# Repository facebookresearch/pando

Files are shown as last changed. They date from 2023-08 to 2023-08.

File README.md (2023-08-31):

# Pando
Pando makes it easy to run experiments with and collect data from several different time tagger and SPAD devices. It supports Brain-Machine Interface research and a recent Nature-published research on **Measuring human cerebral blood flow and brain function with fiber-based speckle contrast optical spectroscopy system** can be found [here](https://www.nature.com/articles/s42003-023-05211-4).

Additional documentation can be found [here](https://github.com/facebookresearch/pando/blob/main/software/doc/sphinx_src/).

# Windows Build Tools Installation
1. Get a windows 10 VM [https://developer.microsoft.com/en-us/windows/downloads/virtual-machines]

2. Install Chocolatey [https://chocolatey.org/install]
3. In an administrator powershell, run:

   ```
   choco install -y python3 --version 3.6.8
   New-Item -ItemType SymbolicLink -Path "C:\Python36\python3.exe" -Target "C:\Python36\python.exe"
   choco install -y git buck python2 visualstudio2017-workload-vctools
   ```
4. Restart

# Runtime Dependencies
Libraries and drivers from various vendors must be installed before certain devices can be used. If the correct runtime dependencies are not installed, the result is usually a hard crash when an attempt to configure one of these devices is made.

All Basler cameras require the Pylon runtime v6.3:
https://www.baslerweb.com/en/downloads/software-downloads/runtime-pylon-6-3-0-windows/

Basler CXP-12 acquisition cards (used with the Basler Boost camera) requre the imaWorx CXP-12 Runtime:
https://www.baslerweb.com/en/downloads/software-downloads/complete-installation-5-9-0-windows-64bit/

The microEnable 5 marathon ACL Frame grabber (used with the Basler acA2000-340kM camera) requires this runtime: 
https://www.baslerweb.com/en/downloads/software-downloads/setup-runtime-5-for-windows-64bit-ver-5-7-0/

The Hamamatsu Orca Fusion requires the "Active Silicon Firebird/Phoenix" component of the DCAM-API:
https://ftp.hostedftp.com/~hamamatsu/DCAM-API/2022/22.9/DCAM-API%20for%20Windows%20(22.9.6509).zip

# Building Pando GUI
Before building Pando, you must generate `software/pando/include/version.h`
```
buck run @mode/win/x86_64/release //software/python/generate_version_header:generate_version_header -- --header --define-name=JULIET_VERSION_STRING >  software/pando/include/version.h
buck build @mode/win/x86_64/release software/python/gui:pando
```

## Mode Files
Buck a has feature called "mode files" (also known as flag files) that allows multiple command line arguments to be supplied at once by passing a path (preceded by an `@`) to a text file containing them. We use this feature to specify various platforms and build types. Our mode files (and the buckconfig files they reference) are stored in `./mode/`.

If you require debug symbols or want to enable asserts, you could instead specify `@mode/win/x86_64/rel_with_deb_info`. If you want an unoptimized debug build, you could specify `@mode/win/x86_64/debug`.

## Using the Correct Toolchain on Windows
Launch "x64 Native Tools Command Prompt for VS 2017" from the start menu. Buck will (apparently) use the environment variables set by this special command prompt to use the right build tools and compile/link against the right windows SDK. Alternatively, run C:\Program Files (x86)\Microsoft Visual Studio\2017\BuildTools\VC\Auxiliary\Build\vcvars64.bat from a normal command prompt.

# Contributors
Mark Spatz, Ryan Catoen, Dan Furie, Jen Dority, Charles Freeman, Jami Friedman, Rudy Sevile and Jimmy Feng.

**License**:
LabGraph is MIT licensed, as found in the LICENSE file.

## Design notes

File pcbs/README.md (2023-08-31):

# Pando Box PCB Repository

This is meant as a central repository of all PCBs created for the Pando Box

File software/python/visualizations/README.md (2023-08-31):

# How to run the Basler and Hamamatsu visualizations from source

## Installing Visualization Source Distribution

0. (First time only) Create a new python virtual environment for running the visualizations.

``` python -m venv C:\vizenv```
1. Activate the visualization virtual python environment you created.

```<drive>:\<virtual-environment-path>\Scripts\activate.bat```

where <drive> and <virtual-environment-path> are replaced by the drive and the path to the virtual environment you created in step 0.

2. Extract all files in visualizations.zip

3. Open a command prompt and change directory to the directory where the contents of the zip file were extracted.

4. ```pip install labgraph\<labgraph-wheel-name>```

where <labgraph-wheel-name> is replaced with the correct name of the "*.whl" file delivered in the "labgraph" directory.

5. ```pip install -r bci\example_requirements.txt```
 
If you get an error building "_yappi" extension, follow instructions under *"Installing Microsoft Visual C++ Build Tools"* now and then rerun this step.

# Installing Microsoft Visual C++ Build Tools

1. go to  https://visualstudio.microsoft.com/downloads/

2. Click top row button *"Free Visual Studio"*

3. Click *"Free Download"* under Visual Studio Community

4. Open downloaded file

5. Allow program to make changes to your computer

6. Under *"Desktop and Mobile"* select *"Desktop Development with C++"*

7. Click *"Install"*

# Running Visualizations

## Running Visualizations from the command line

First, make sure you have activated the python virtual environment you created for visualizations.

```<drive>:\<virtual-environment-name>\Scripts\activate.bat```

where <drive> and <virtual-environment-path> are replaced by the drive and the path to the virtual environment you created

**Run the visualizations from the directory where the visualizations.zip contents were extracted.**

Depending on the camera mode and the choice of tcp port, the full command for running the visualization software will likely look something like

```python -m bci.libraries.labgraph_viz.bassler_hamamatsu_viz --camera-mode basler```

The `-m` flag specifies that the script is to be run as a module.  The visualizations will not work without this flag.

`bci.libraries.labgraph_viz.bassler_hamamatsu_viz` is the relative path of the visualization module from the root directory of the visualizations folder.

## Choosing Camera Mode

The `--camera-mode basler` flag informs the visualization software that the message field types and the sizes of the heatmaps should be fitted for basler sized images.  To run the visualizations in hamamatsu mode, change this command to `--camera-mode hamamatsu`.

## Changing the TCP port

There is an optional flag that can be appended to change the tcp port where the visualizations receive incoming messages.  By default, the visualizations expect the messages to appear at `tcp://127.0.0.1:5060`.  However, in order to run both the visualizations for both basler and hamamatsu at the same time, one must ensure that each instance receives the messages at different ports.  This can be accomplished by including the flag `--read-addr tcp://127.0.0.1:5061`.  For instance, one could run the hamamatsu visualizations from messages coming through `tcp://127.0.0.1:5061` using the full command

```python -m bci.libraries.labgraph_viz.bassler_hamamatsu_viz --camera-mode hamamatsu --read-addr tcp://127.0.0.1:5061```

The ability to specify which port the messages are arriving at allows us to run the basler and hamamatsu visualizations in parallel.  Running the two commands

```python -m bci.libraries.labgraph_viz.bassler_hamamatsu_viz --camera-mode basler```

```python -m bci.libraries.labgraph_viz.bassler_hamamatsu_viz --camera-mode hamamatsu --read-addr tcp://127.0.0.1:5061```

concurrently allows for both visualization modes to run concurrently with no conflicts.

# Using the Visualizations

When the visualizations are run, two separate windows should pop up.  One consists of four panels displaying live visualizations for the running camera.  The other is a Region of Interest Selection Utility.

To activate a region of interest in the RoI popup, drag on one of the handles in the upper right or bottom left of the camera live feed.  This will activate (and resize) a region of interest.  The RoI can further be repositioned by clicking and dragging.  Associated updates in the visualizations can be observed upon RoI activation.  

In general, try not to activate any more RoI's than are needed for the experiment.  Calculating the contrast of each region is taxing, and activating too many might lead to performance or stability issues.

Two spinboxes can also be found in the visualization suite.  The one within the RoI popup dictates how long of a rolling average window to maintain.  The one within the main four-panel graph dictates how large of a rolling average window to maintain, as used in normalizing the values when computing the contrast.  Neither of these parameters should have a drastic impact on performance.

Finally, for the sake of stability, try not to run any intensive applications in parallel with the visualizations.  They are very computationally intensive programs that run with stability when run standalone, but using them in conjunction with other high or medium intensity programs, such as heavy duty IDE's or some browsers, might lead to performance issues.  So, avoid this when possible.

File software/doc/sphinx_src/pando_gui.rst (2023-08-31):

.. cpp:namespace:: pnd::pando

==========
Pando GUI
==========
The Pando GUI is a frontend for libpando that presents all of the available settings in a (hopefully) intuitive format.

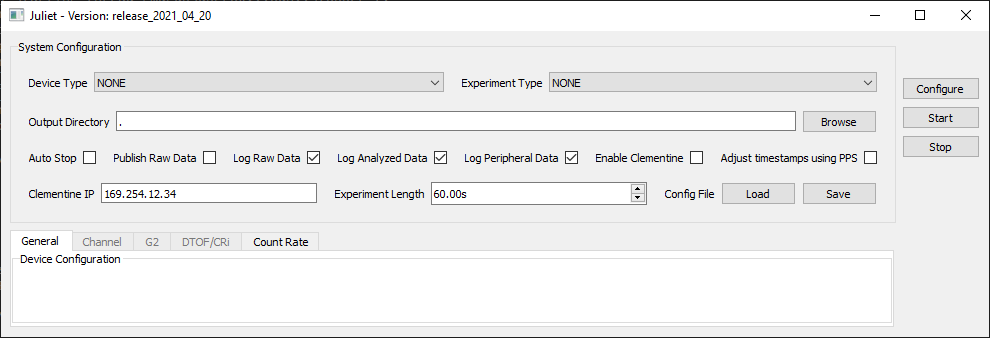
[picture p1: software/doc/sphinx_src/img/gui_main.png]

   
   Screenshot of the Pando GUI

Experiment Control
------------------
Configure
  Applies the current configuration as specified by all other GUI elements.
  Settings don't take effect until either **Configure** or **Start** is clicked.
  See :cpp:func:`PandoInterface::Configure`

Start
  Applies the current configuration, then starts a new experiment.
  See :cpp:func:`PandoInterface::Start`

Stop
  Stop the current experiment and wait until all in-flight data has been written to the HDF5 files.

System Configuration Pane
-------------------------

Config file
  Load/save all settings (from all panes, visible or not) to a YAML file.

.. list-table::
   :header-rows: 1

   * - Setting
     - Description
   * - Device Type
     - See :cpp:member:`PandoInterface::Config::device`
   * - Experiment Type
     - See :cpp:member:`PandoInterface::Config::exp_type`
   * - Output Directory
     - See :cpp:member:`PandoInterface::Config::output_dir`
   * - Auto Stop
     - See :cpp:member:`PandoInterface::Config::auto_stop`
   * - Publish Raw Data
     - See :cpp:member:`PandoInterface::Config::publish_raw_data`
   * - Log Raw Data
     - See :cpp:member:`PandoInterface::Config::log_raw_data`
   * - Log Analyzed Data
     - See :cpp:member:`PandoInterface::Config::log_analyzed_data`
   * - Log Peripheral Data
     - See :cpp:member:`PandoInterface::Config::log_peripheral_data`
   * - Enable Pandoboxd
     - See :cpp:member:`PandoInterface::Config::use_pandoboxd`
   * - Adjust timestamps using PPS
     - See :cpp:member:`PandoInterface::Config::use_pps`
   * - Pandoboxd IP
     - See :cpp:member:`PandoInterface::Config::pandoboxd_ip_addr`
   * - Experiment Length
     - See :cpp:member:`PandoInterface::Config::experiment_length`

General Tab
-----------

Settings related to general device operation.

.. list-table::
   :header-rows: 1

   * - Setting
     - Description
   * - Enabled Channels
     - See :cpp:member:`PandoInterface::Config::enabled_channels`
   * - Laser Sync Rep Period
     - See :cpp:member:`PandoInterface::Config::laser_sync_period_ps`
   * - Sync Divider
     - See :cpp:member:`PandoInterface::Config::xharp_sync_div`

Channel Tab
-----------
Settings related to the individual input channel frontends of PicoQuant devices.

.. list-table::
   :header-rows: 1

   * - Setting
     - Description
   * - Sync (Channel 0) CFD level
     - See :cpp:member:`PandoInterface::Config::xharp_sync_level`
   * - Sync (Channel 0) Zero Crossing level
     - See :cpp:member:`PandoInterface::Config::xharp_sync_zerox`
   * - Channel CFD level
     - See :cpp:member:`PandoInterface::Config::xharp_level`
   * - Channel Zero Crossing
     - See :cpp:member:`PandoInterface::Config::xharp_zerox`
   * - Channel Zero Crossing
     - See :cpp:member:`PandoInterface::Config::xharp_zerox`
   * - Channel Offsets
     - See :cpp:member:`PandoInterface::Config::hharp_input_offsets`

The MultiHarp has unique channel settings (the inputs don't have CFDs):

.. list-table::
   :header-rows: 1

   * - Setting
     - Description
   * - Sync Trigger Edge
     - See :cpp:member:`PandoInterface::Config::multi_harp_sync_trigger_edge`
   * - Sync Trigger Level
     - See :cpp:member:`PandoInterface::Config::multi_harp_sync_trigger_level_mv`
   * - Sync Tdead
     - See :cpp:member:`PandoInterface::Config::multi_harp_sync_tdead_ps`
   * - Trigger edges
     - See :cpp:member:`PandoInterface::Config::multi_harp_sync_trigger_edge`
   * - Trigger Levels
     - See :cpp:member:`PandoInterface::Config::multi_harp_trigger_level_mv`
   * - Tdead
     - See :cpp:member:`PandoInterface::Config::multi_harp_tdead_ps`

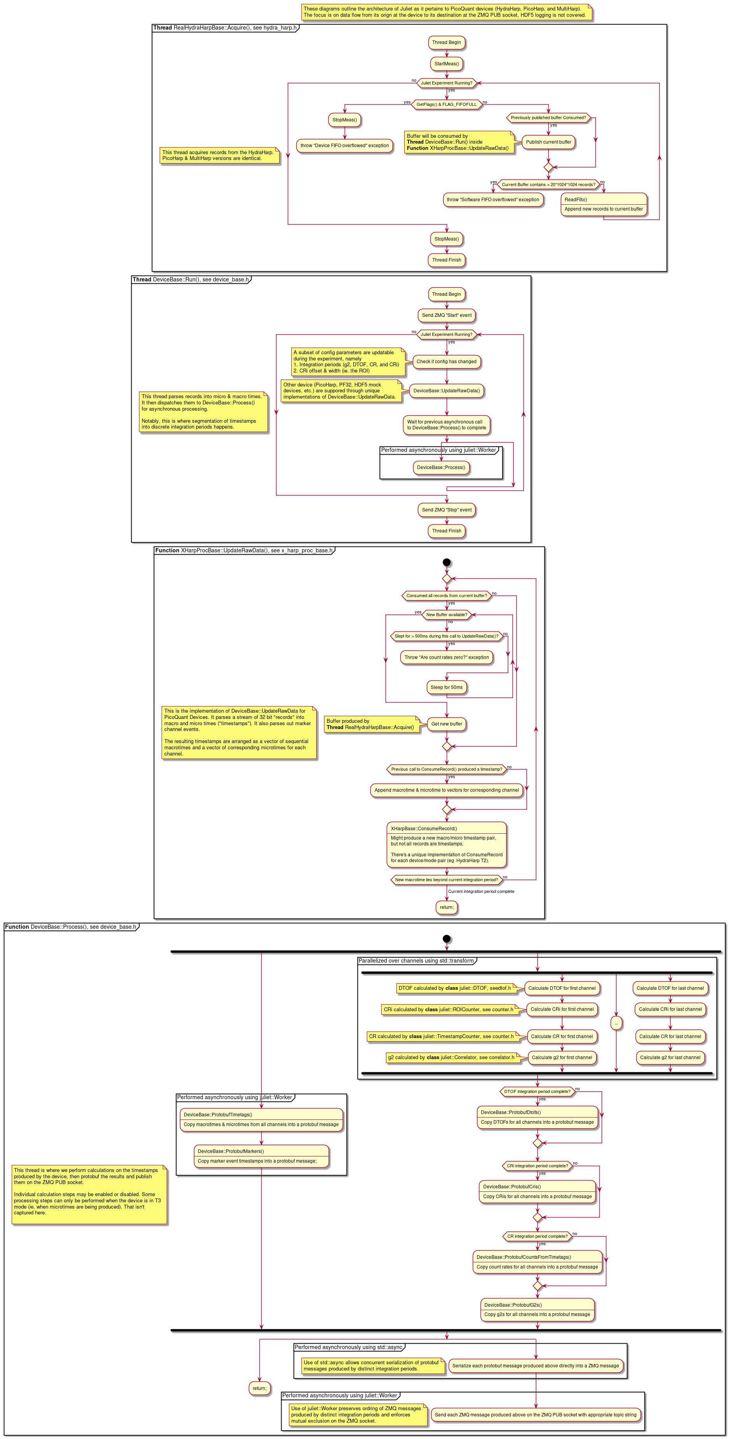
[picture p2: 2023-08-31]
software/pando/doc/architecture.png

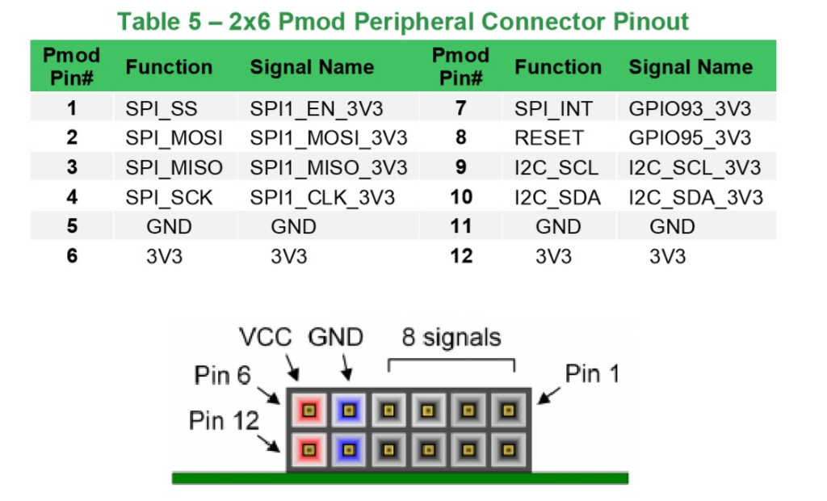
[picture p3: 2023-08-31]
pcbs/SPItoLVDS/Documentation/pmod_pinout.png

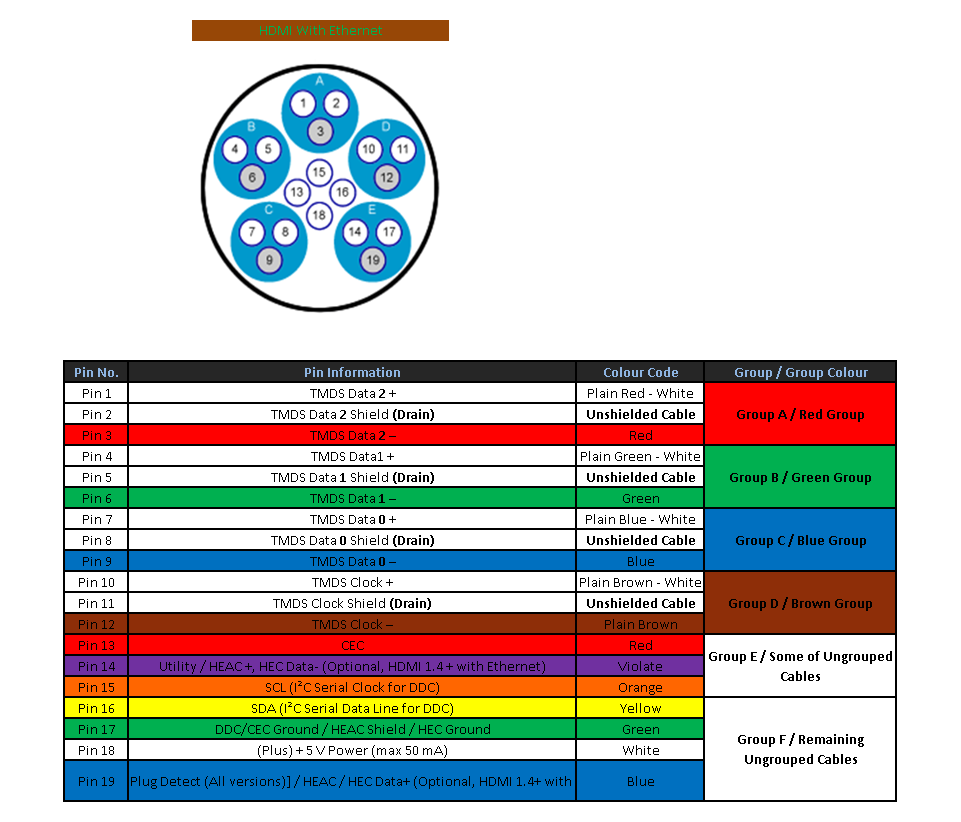
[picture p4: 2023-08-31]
pcbs/RemoteIMU/Documentation/hdmi_pinout.png

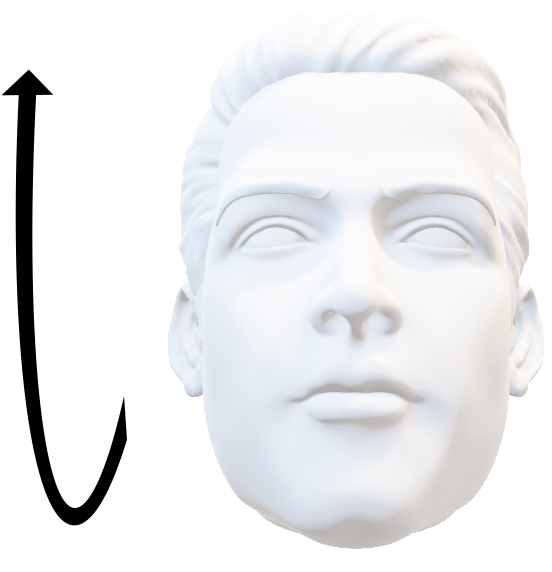
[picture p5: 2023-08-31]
software/python/visualizations/bci/stimulus/psychopy/images/files/pitch_up.png

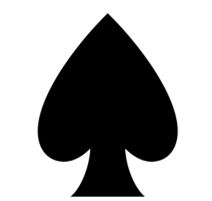
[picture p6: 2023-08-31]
software/python/visualizations/bci/stimulus/psychopy/images/files/spade.png

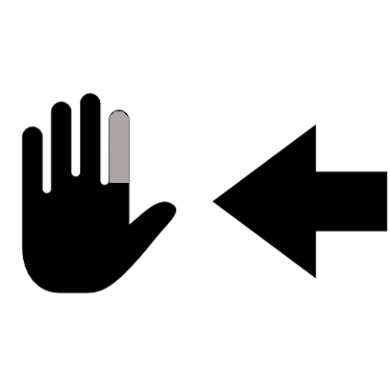
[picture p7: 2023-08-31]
software/python/visualizations/bci/stimulus/psychopy/images/files/index_left.png

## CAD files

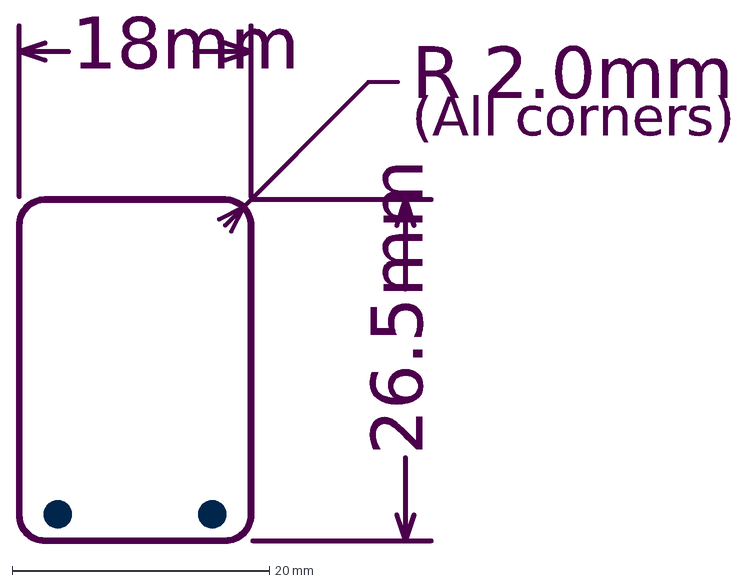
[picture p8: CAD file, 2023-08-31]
pcbs/RemoteIMU/soho_imu_outline.DXF
(All corners)
R 2.0mm
26.5mm
18mm

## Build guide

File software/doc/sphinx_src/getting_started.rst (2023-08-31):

.. cpp:namespace:: pnd::pando

==========
Getting Started with Pando
==========
Pando makes it easy to run experiments with and collect data from several different time tagger and SPAD devices.

This guide will take you step-by-step through running experiments with real devices.

Prerequisites
-------------
Pando runs on Windows and is built as Python pex executable. It requires Python 3 to be installed on the Windows PC.

You must install the drivers for the devices you will be working with.

You must install the latest Microsoft Visual C++ Redistributable for Visual Studio from `here <https://support.microsoft.com/en-us/topic/the-latest-supported-visual-c-downloads-2647da03-1eea-4433-9aff-95f26a218cc0>`_.

Starting Pando
---------------
Open a command prompt (cmd.exe) and navigate to the directory where the pando.pex file is located.

At the prompt, run the command ``python pando.pex``.

The Pando GUI will open: 


   
   Screenshot of the Pando GUI

Selecting a Device and Experiment Type
--------------------------------------
The device and experiment types chosen will determine the what options and defaults are available in some parts of the GUI. For this tutorial, we will be running a TD experiment with PicoQuamt's MultiHarp device.

Once you have set the the device and experiment types, the GUI will update to accommodate devices-specific settings.

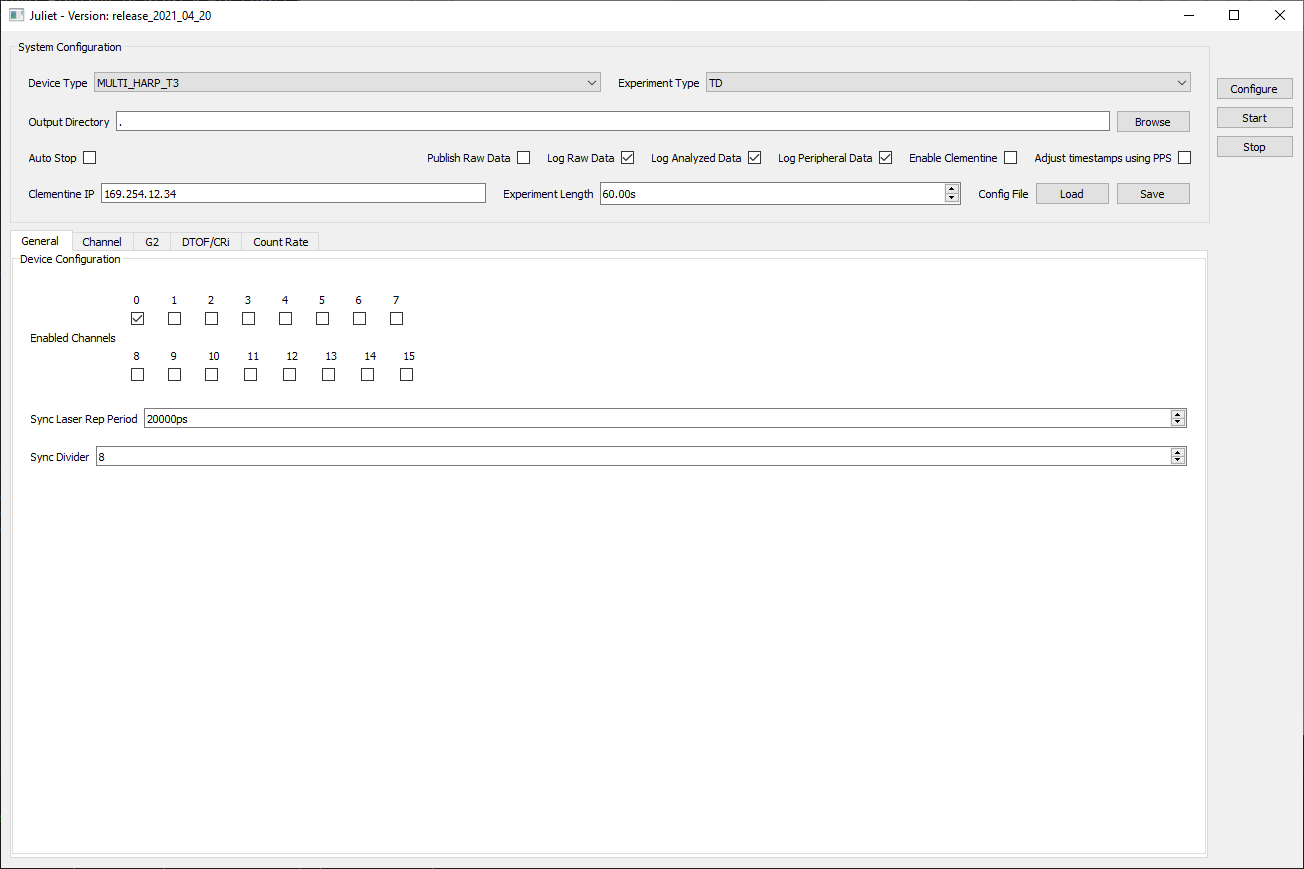
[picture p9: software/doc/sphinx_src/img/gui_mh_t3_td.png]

   
   Pando GUI with Device Type "MULTI_HARP_T3" and Experiment Type "TD" selected

Channel Selection and General Device Configuration
--------------------------------------------------
On the "General" tab in the device configuration section, select the channels to be used by checking the corresponding checkboxes in the "Enabled Channels" area. Data from unselected channels will be ignored. Set an appropriate Sync Divider value, and also the correct Sync Laser Rep Period -- the time in picoseconds between two consecutive sync pulses.

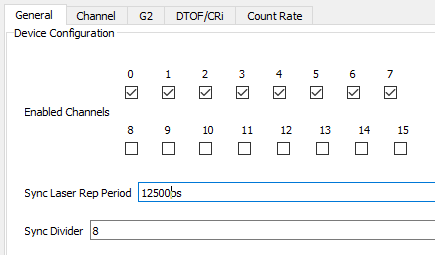
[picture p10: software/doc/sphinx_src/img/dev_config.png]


   Enabled Channels, Sync Laser Rep Period and Sync Divider settings in the "General" tab

Input Channel Configuration
---------------------------
Next, configure the settins per input channel. The settings available on "Channel" ta vary significantly depending on the device type selected. For the MultiHarp device, make sure the Channel Offsets, Trigger Edges, Trigger Levels and programmable dead times are correct for each channel.

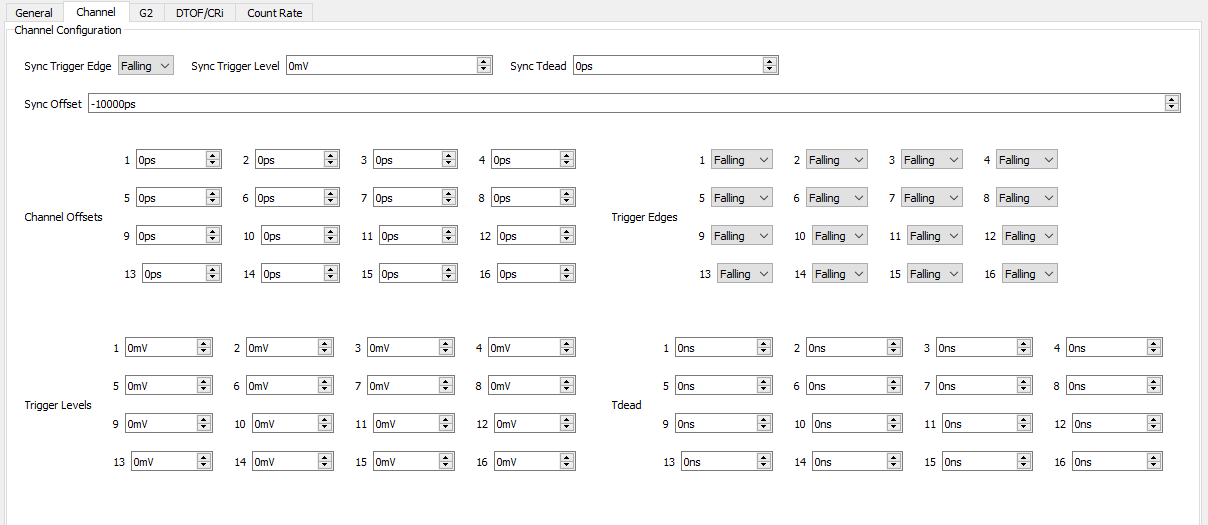
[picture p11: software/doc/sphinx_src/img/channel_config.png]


   Input Channel Configuration for MultiHarp on "Channel" Tab

G2, DToF and CRi
----------------
The last three tabs in the Device Configuration Panel allow you to set parameters for their respective calculations.

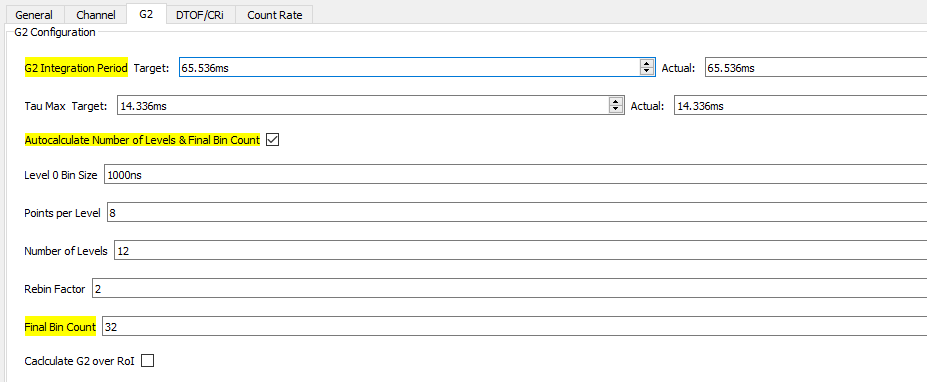
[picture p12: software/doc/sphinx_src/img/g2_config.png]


   G2 Configuration Parameters

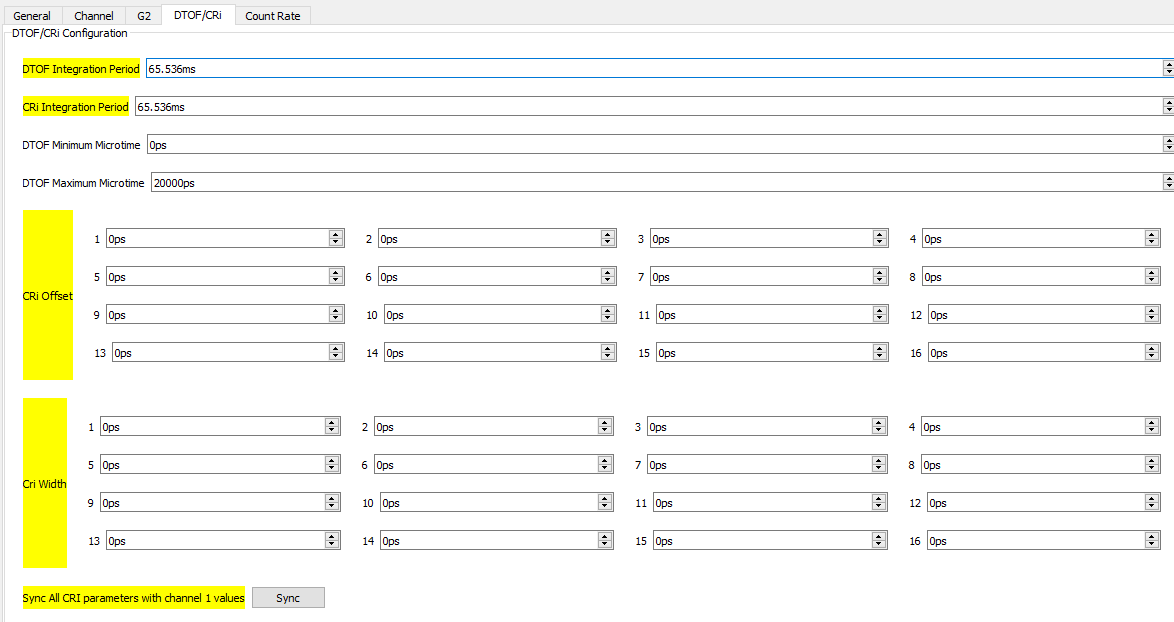
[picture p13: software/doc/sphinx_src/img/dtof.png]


   DToF Configuration Parameters

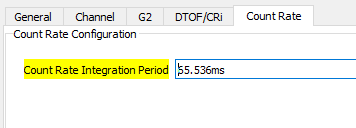
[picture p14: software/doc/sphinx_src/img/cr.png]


   Count Rate Configuration Parameters

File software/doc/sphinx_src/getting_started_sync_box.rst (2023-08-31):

.. cpp:namespace:: pnd::pando

==========
Getting Started with the Sync Box
==========

Ultrazed Setup
--------------
Below is an overview image of the internals of the Sawyer Sync Box, which consists of the UltraZed-EG with IO Carrier card and peripheral interface boards.  Relevant components are labelled.

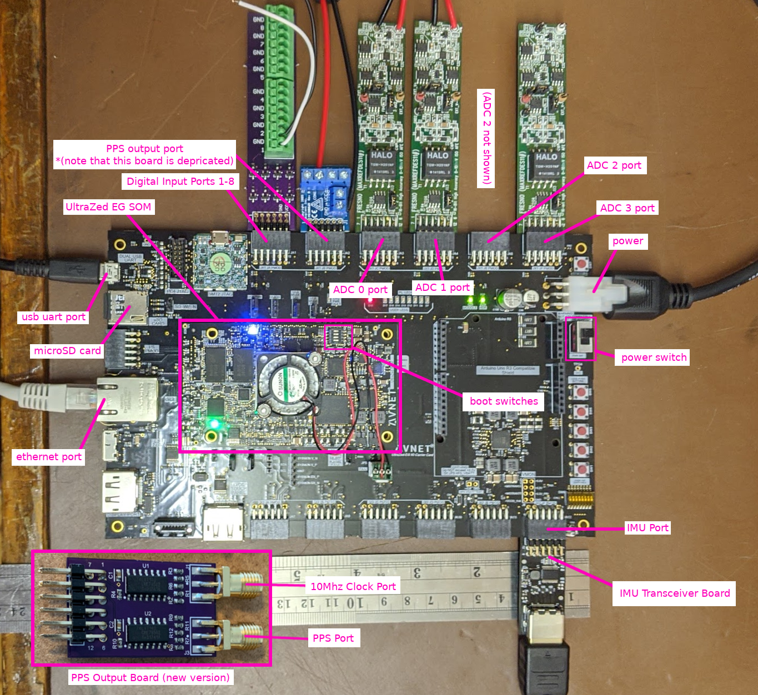
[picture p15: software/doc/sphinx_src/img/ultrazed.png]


PMOD Boards
^^^^^^^^^^^
There are 7 PMOD devices that must connect to specific ports on the Ultrazed:

1. The IMU transceiver board, which interfaces with the IMU over an HDMI cable. Plug into the JX2 JF PMOD port on the carrier card.
2. The digital input interface board, which breaks out the 8 digital input channels. Plug into JX1 JA PMOD port.
3. PPS output breakout board, which breaks out the PPS signal to be plugged into the timetagger device. Plug into JX1 JB PMOD port.
4. ADC 0, which receives analog input. Plug into JX1 JC PMOD port.
5. ADC 1, which receives analog input. Plug into JX1 JD PMOD port.
6. ADC 2, which receives analog input. Plug into JX1 JE PMOD port.
7. ADC 3, which receives analog input. Plug into JX1 JF PMOD port.

Boot Switches
^^^^^^^^^^^^^
In order to make the board boot from SD card, the boot switches on the UltraZed board must be set appropriately (location of the switches is indicated in the above overview image). The switch settings are: 1: OFF/down, 2: ON/up, 3: OFF/down, 4: ON/up.

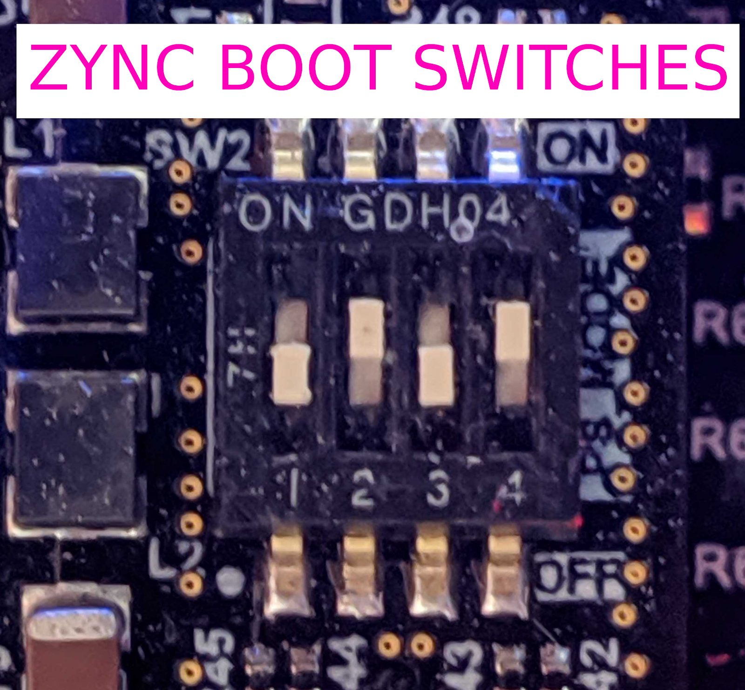
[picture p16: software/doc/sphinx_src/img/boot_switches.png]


SD Card
^^^^^^^
A microSD card will be provided by LeafLabs that is used to boot the board. The most-up-to-date image for the board plus the current build of Pandoboxd (the board-side data acquisition application) will also be provided. If updated software is required, LeafLabs will provide new images and/or Pandoboxd executables. The SD card is FAT format and should not be reformatted. The boot files must be copied onto the SD card and any old files removed. The required files are image.ub, BOOT.bin, and pandoboxd (a linux executable). Please note that the pandoboxd executable must be named “pandoboxd” exactly, or the executable will not be run automatically after booting.

Networking
^^^^^^^^^^
By default, the UltraZed board is configured to use a fixed ipv4 link-local address: 169.254.12.34.  The preferred method to connect is to directly connect an ethernet cable to a  NIC attached to the target control PC.

If using Linux, you may need to configure your network interface to use link-local IPV4 addressing.

* Open the network management dialog, select your ethernet adapter, and press configure (location varies by distribution)
* On the IPV4 tab, change "method" to "Link-Local Only"

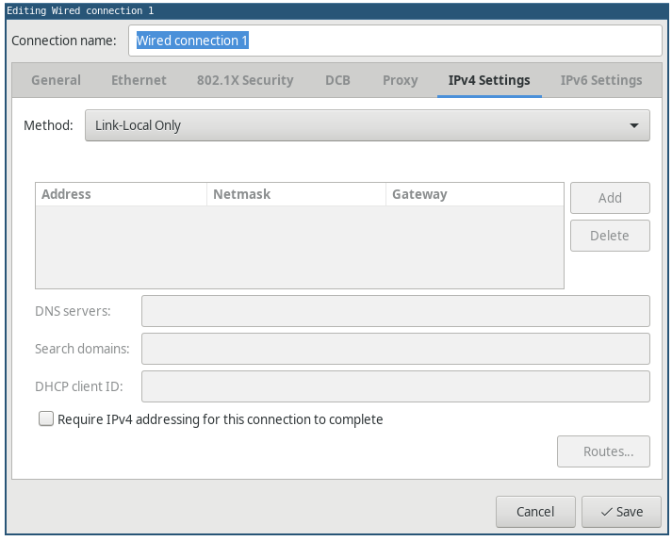
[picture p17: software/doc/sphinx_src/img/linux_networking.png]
  * 

* You should be able to see a link-local address via "ifconfig"
  
  * 
  * (Note the inet prefix 160.254)

On most recent versions of windows, acquiring a link-local address should be automatic, however it may be necessary to execute the command ipconfig /renew in a command prompt in order for the changes to take effect.

Power
^^^^^
The provided UltraZed power cable should be inserted into the board. The master power switch is located next to the power socket.

USB UART Terminal
^^^^^^^^^^^^^^^^^
(note: this section is not important for setup; the UART interface will not need to be used under normal circumstances. This information is provided for future reference only)

If a terminal interface to the UltraZed is ever required, there is a microUSB port labeled “Dual USB UART” on the board which can be used to establish a connection between the board and a PC. The terminal can be used via a terminal program such as screen or teraterm at a baud rate of 115200. See here for additional details. The default credentials for the board are username: root, password: root.

Connecting to Peripherals and Timetagger Devices
------------------------------------------------

Digital Inputs
^^^^^^^^^^^^^^
Digital signals must be input into one of the eight broken-out channels on the Digital Input PMOD interface board. These signals must be properly driven digital signals, between 3.3V and 5V. Ensure that each signal is grounded to one of the eight ground connectors.

ADCs
^^^^
Each ADC board accepts one analog signal. Signals must be between 0V and 10V. Some of the ADCs have a BNC female connector, while others have loops for clips or probes. Note that the input of the ADC is isolated from the board-side, so the input signals should not be grounded to the board.

IMU
^^^
The IMU board is connected to the IMU transceiver via an HDMI-to-microHDMI cable. The cable should not be in excess of 25 feet.

PPS Output
^^^^^^^^^^
The sync box generates a 1Hz PPS signal that must be connected to the desired timetagger device in order to synchronize experiments with the sync box peripherals. The PPS breakout board attached to the UltraZed outputs the PPS signal via a BNC female connector. This Timetagger-device-side connector is slightly different for each device:

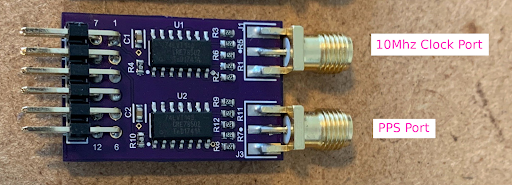
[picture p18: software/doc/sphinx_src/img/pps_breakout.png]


HydraHarp
"""""""""
The PPS signal should be attached to Marker Channel 1 on the Hydra Harp. The marker channels have NIM-CAMAC female connectors. A NIM male - SMA male cable is needed to interface the PPS signal with the marker channel port.

PicoHarp
""""""""
The PicoHarp’s marker channels are accessed via the RT port. A mate for this port with marker channel 0 broken out to BNC female is shown in the illustration below. A BNC male - SMA male cable is needed to interface the PPS signal with the port.

The connector for the RT port is a 15-pin DSUB male connector. The pinout of the provided adaptor is shown in the image below if additional units are needed.

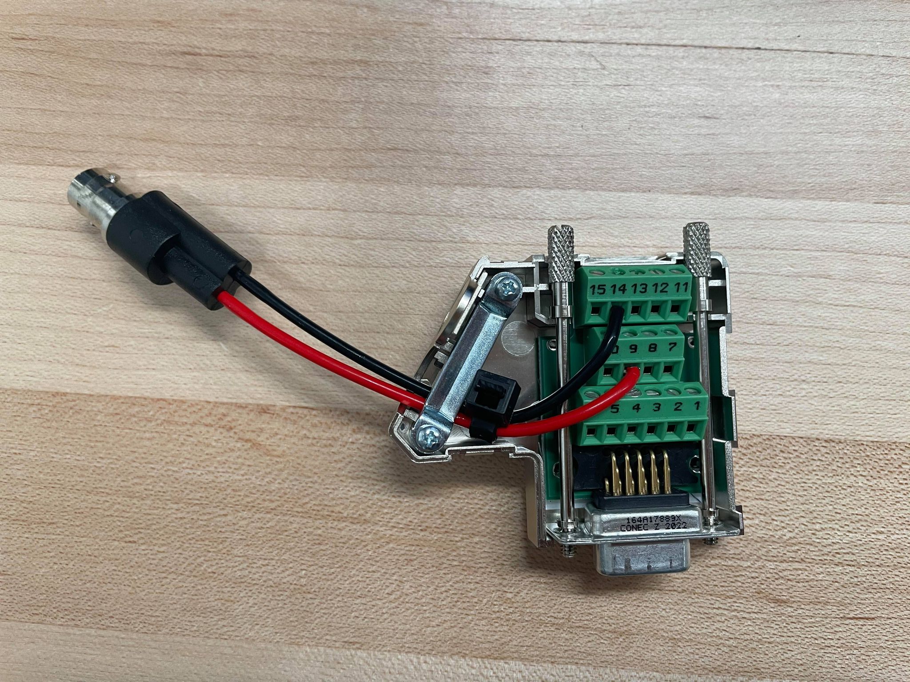
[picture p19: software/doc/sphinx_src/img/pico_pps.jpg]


MultiHarp
"""""""""
The MultiHarp’s marker channels are accessed via the CTRL port. A mate for this port with marker channel 1 broken out to BNC female is shown in the illustration below. A BNC male - SMA male cable is needed to interface the PPS signal with the port.

The connector for the CTRL port is a 25-pin DSUB. The pinout of the provided adaptor is shown in the image below if additional units are needed.

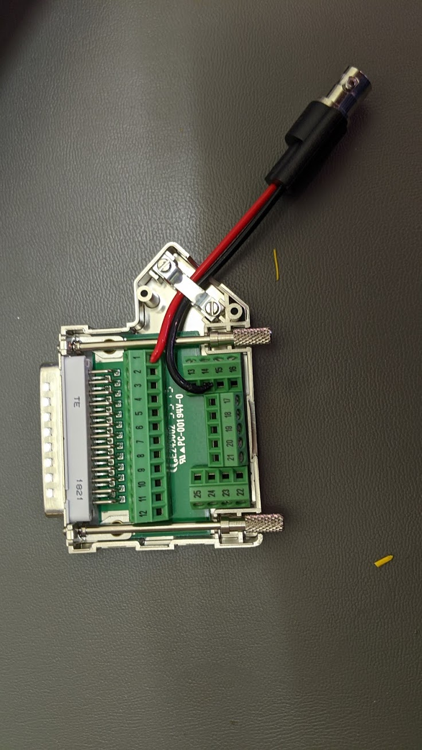
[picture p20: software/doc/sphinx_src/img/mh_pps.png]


PF32
""""
The PPS signal should be attached to the PF32’s “PIXEL” input. An SMA male - SMA male cable is needed to interface the PPS signal with the port.

Running an Experiment
---------------------
1. Ensure that the board is set up as described in the above section. Ensure that the network is properly configured. Ensure that the SD card with current image and pandoboxd executable is inserted.
2. Attach all desired peripherals to their corresponding PMOD peripheral interface.
3. Attach PPS signal to the desired timetagger device.
4. Connect timetagger device to host PC.
5. Power on sync box and timetagger device.
6. Run pando on host PC. Configure Pando to use PPS, use Pandoboxd, and enter the correct IP address of Pandoboxd (found in the network section above).
7. Start the experiment with desired parameters.

To run a sync box experiment without a TImetagger device, select Device Type: NONE and Experiment Type: NONE while configuring pando.

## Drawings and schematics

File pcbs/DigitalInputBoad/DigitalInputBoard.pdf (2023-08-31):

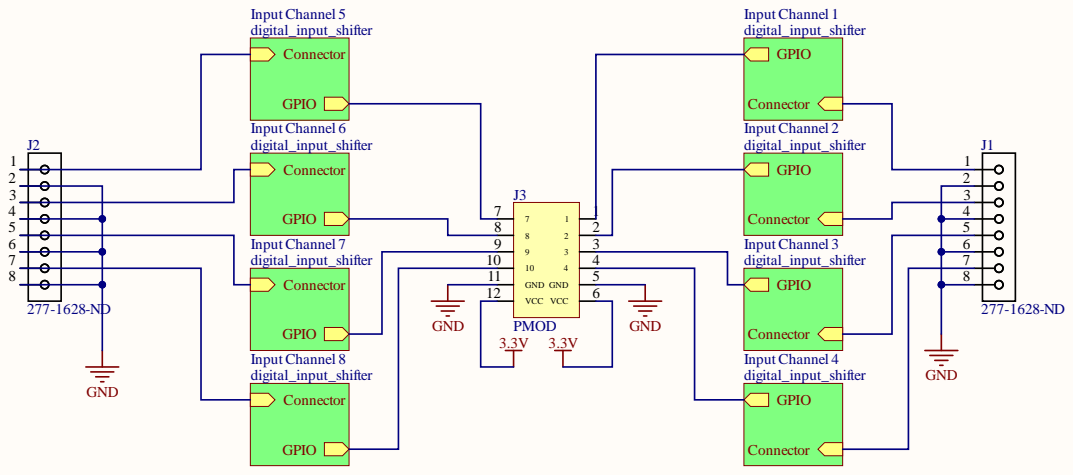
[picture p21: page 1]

In p u tChan n e l 7 9 | | 3 In p u tChan n e l 3 | i ft er

Co n n e c t o r GPI O | 1 | 1 | | 5 | GPI O Co n n e c t o r

T IT L E Di g ita l I n p ut Bre ak o ut Bo ard

PRO J Saw yer | CL IE N T Faceb o o k

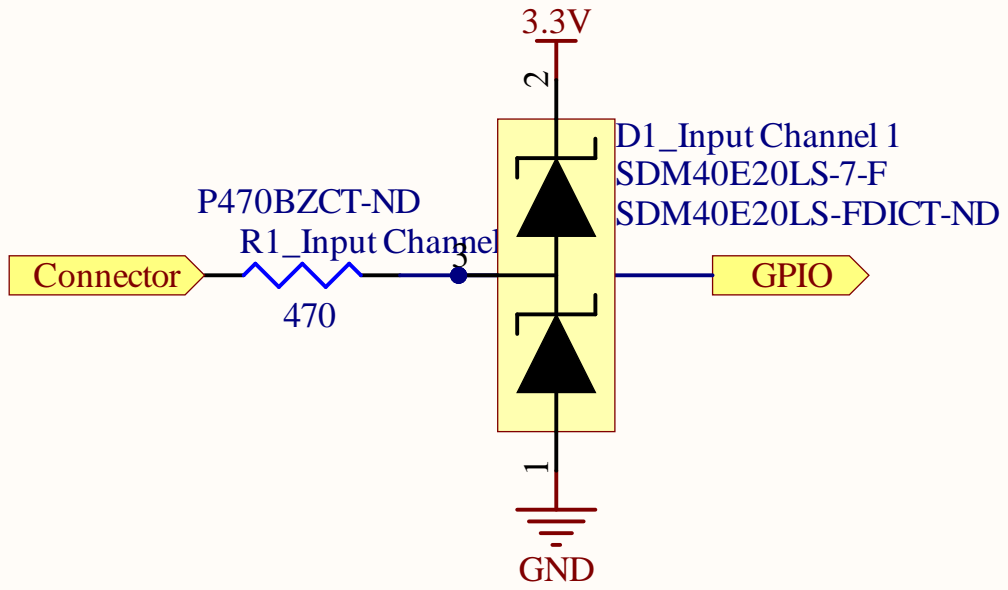
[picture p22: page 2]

TITLE Digital Input Breakout Board - Level Clipper

PROJ Sawyer | CLIENT Facebook

REV | DATE

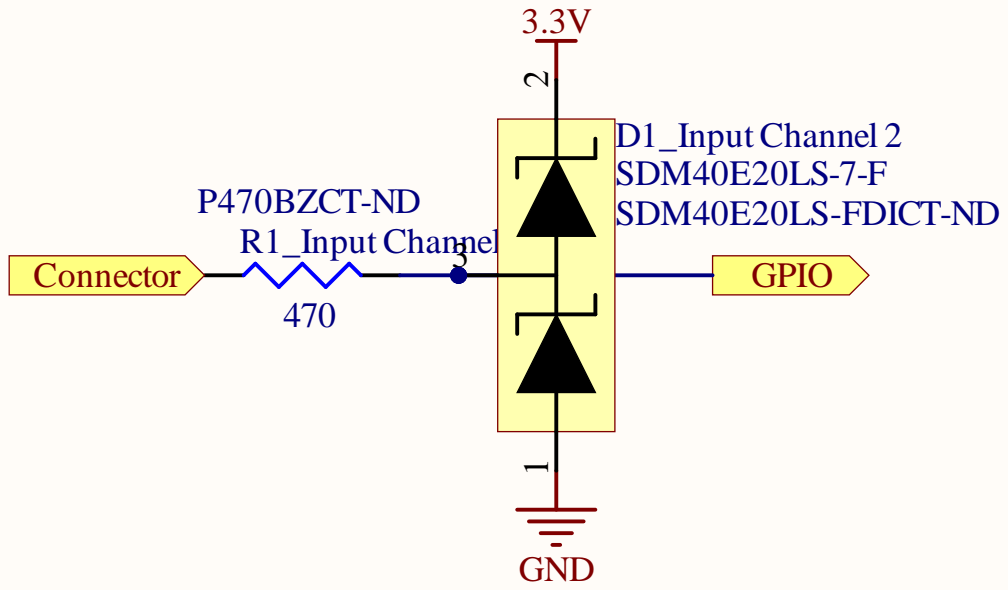
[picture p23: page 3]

TITLE Digital Input Breakout Board - Level Clipper

PROJ Sawyer | CLIENT Facebook

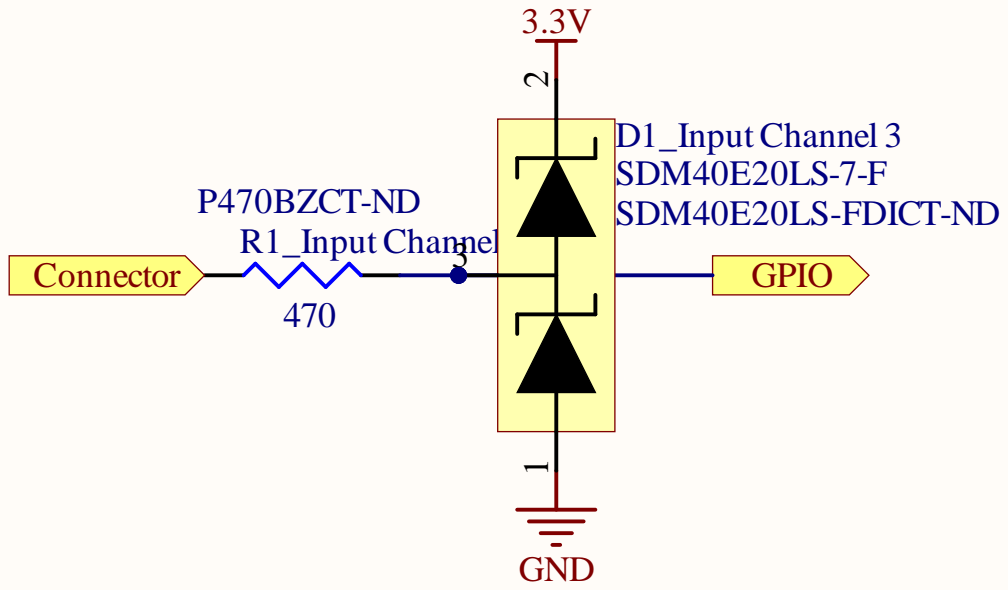
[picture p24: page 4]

TITLE Digital Input Breakout Board - Level Clipper

PROJ Sawyer | CLIENT Facebook

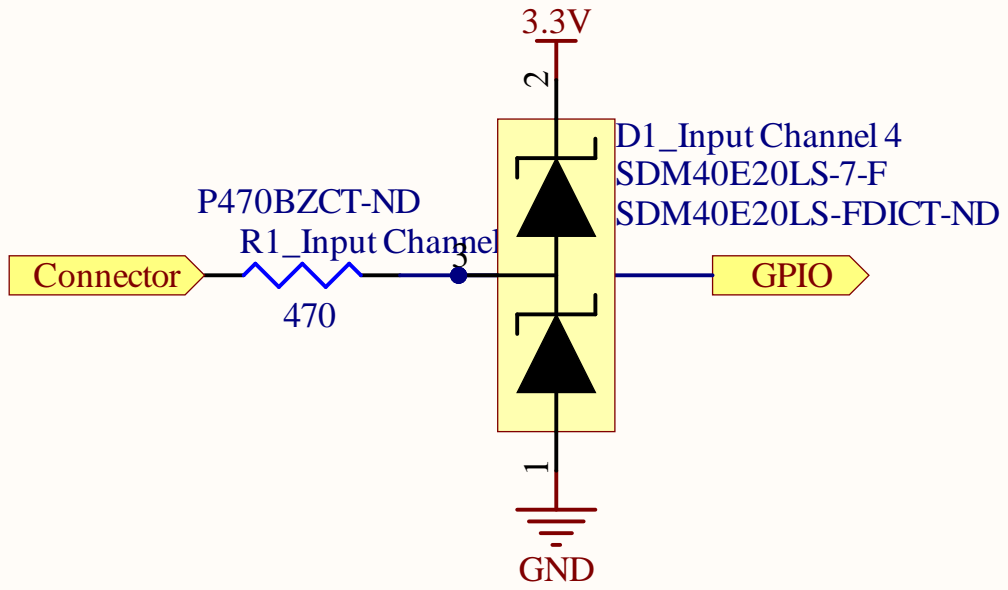
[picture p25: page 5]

TITLE Digital Input Breakout Board - Level Clipper

PROJ Sawyer | CLIENT Facebook

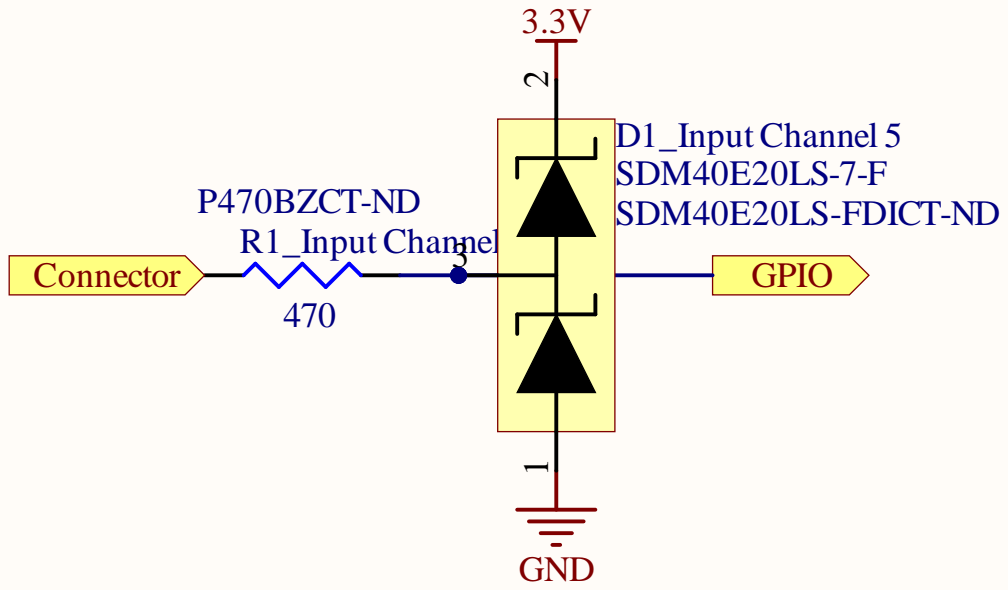
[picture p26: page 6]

TITLE Digital Input Breakout Board - Level Clipper

PROJ Sawyer | CLIENT Facebook

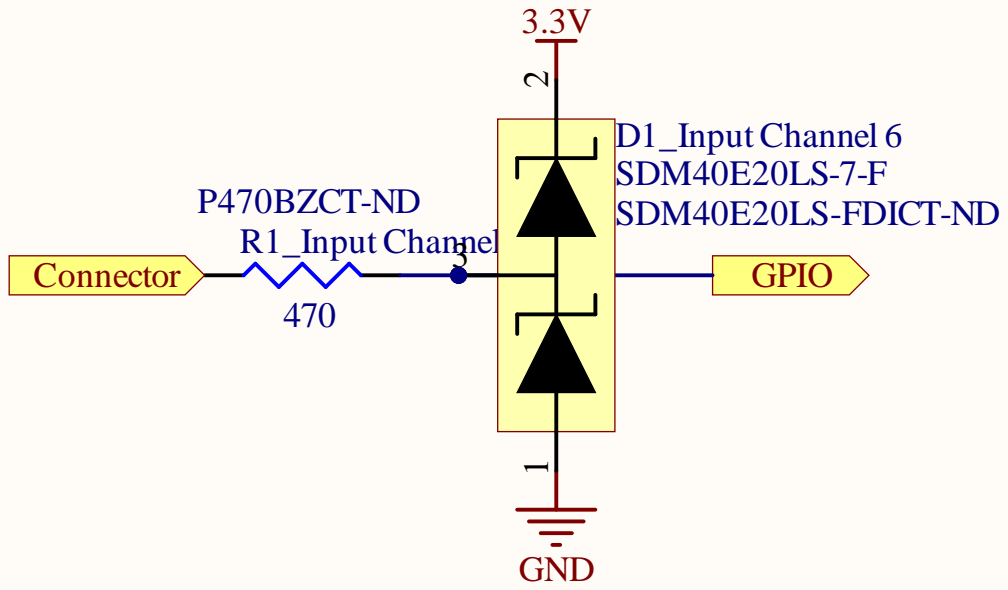
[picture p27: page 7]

TITLE Digital Input Breakout Board - Level Clipper

PROJ Sawyer | CLIENT Facebook

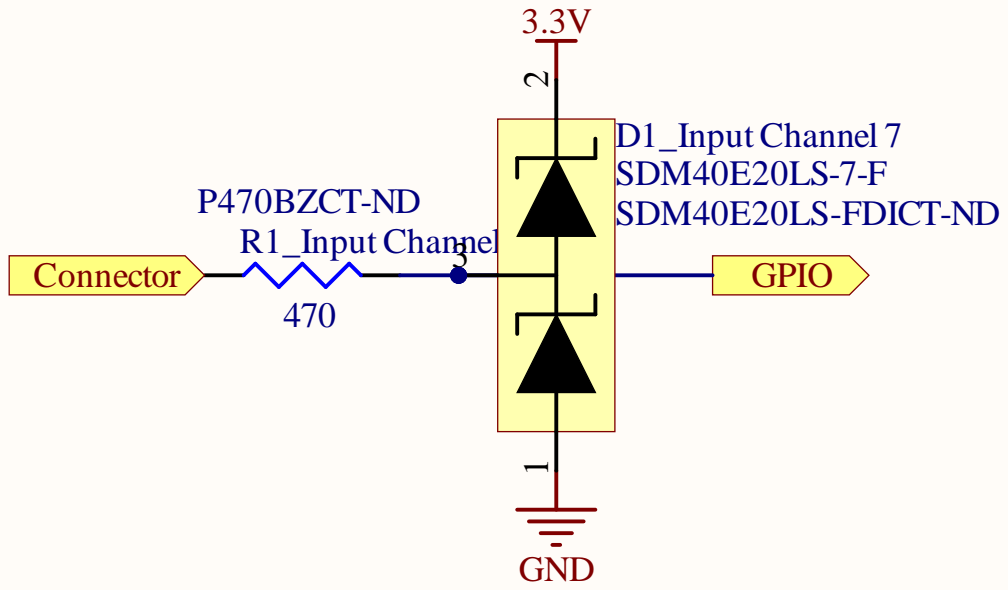
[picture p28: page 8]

TITLE Digital Input Breakout Board - Level Clipper

PROJ Sawyer | CLIENT Facebook

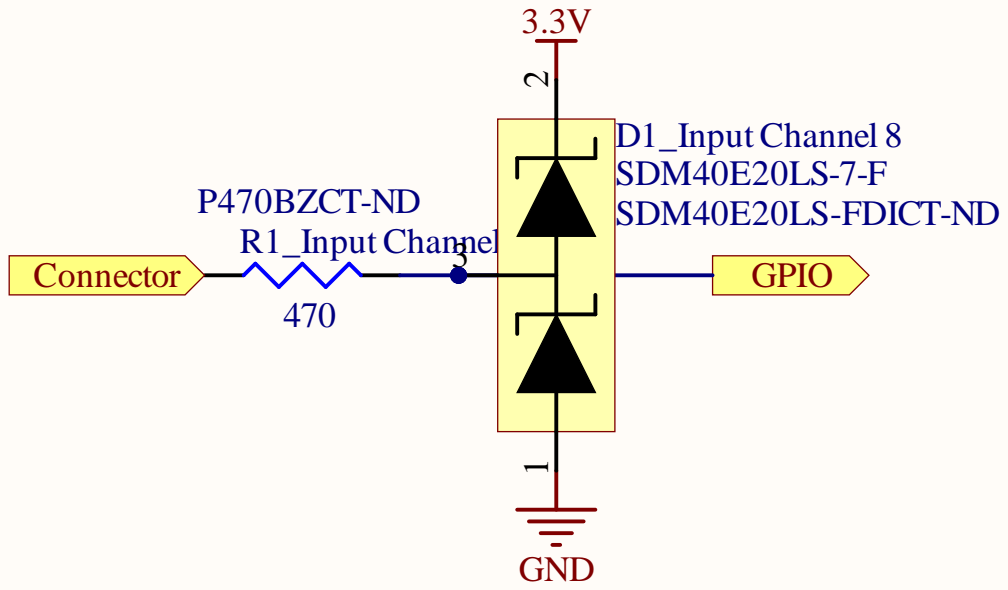
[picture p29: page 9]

TITLE Digital Input Breakout Board - Level Clipper

PROJ Sawyer | CLIENT Facebook

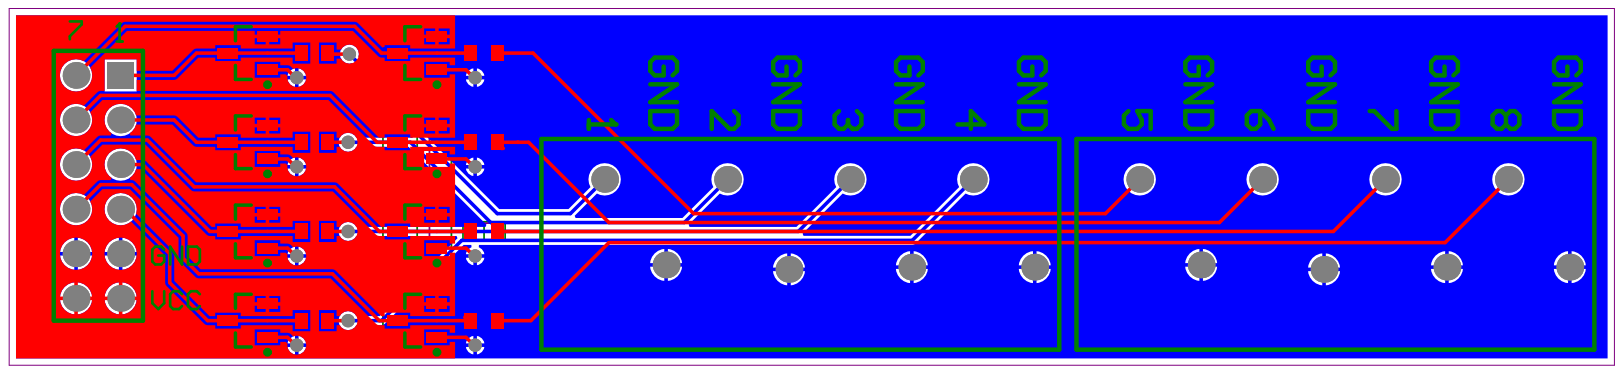
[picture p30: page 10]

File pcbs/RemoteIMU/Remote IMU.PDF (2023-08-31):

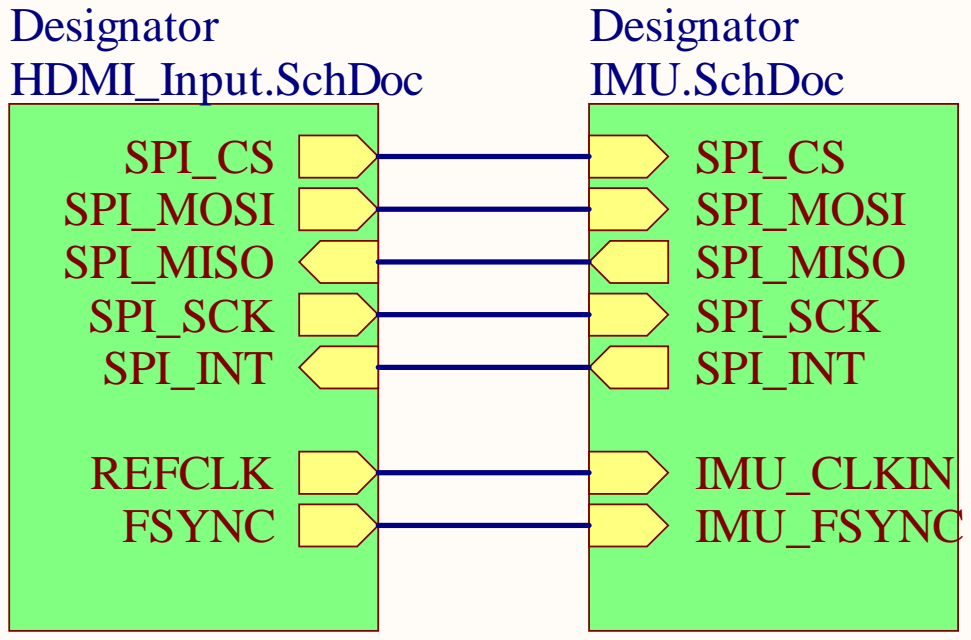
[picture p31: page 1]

TITLE Remote IMU

PROJ Sawyer | CLIENT Facebook

REV 1 | DATE 6/12/2020

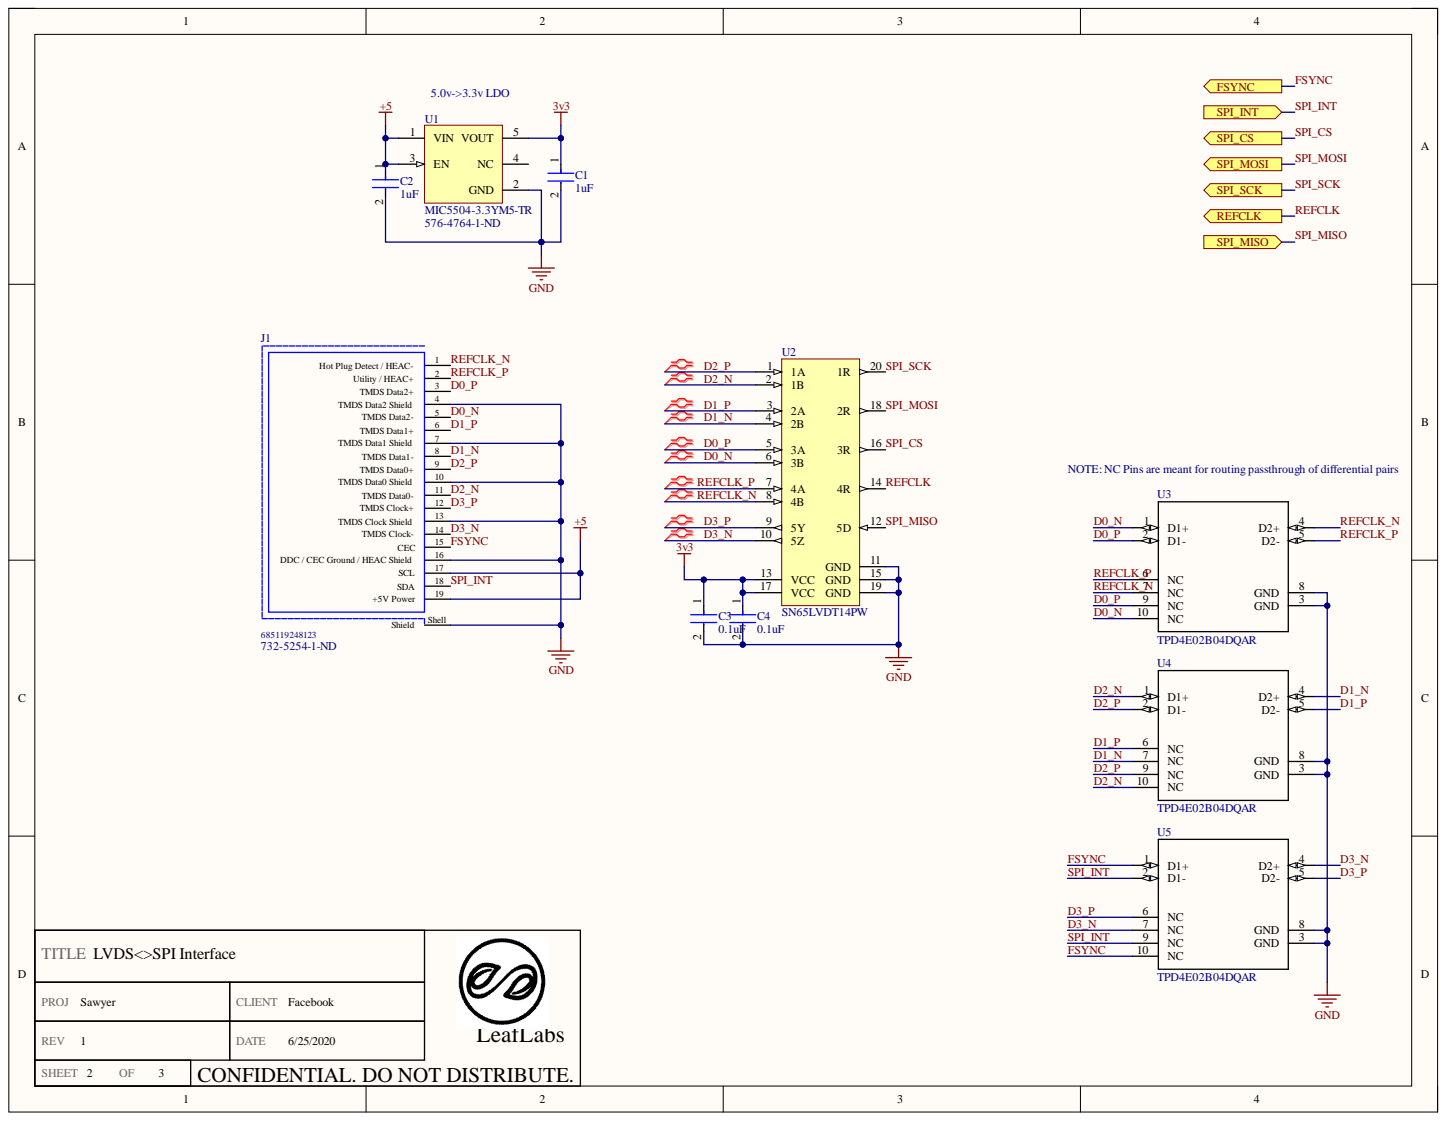
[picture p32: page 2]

1 7
1 8 | SPI _ IN T

PRO J Saw yer | CL IE N T Faceb o o k


T IT L E MPU6 0 0 0 IMU

PRO J Saw yer | CL IE N T Faceb o o k






Comment | Description | Designator | Quantity | Supplier Part Number 1

1uF | CAP CER 1UF X7R 0603 | C1, C2 | 2 1276-1036-1-ND

0.1uF | CAP CER 0.1UF 16V X7R 0603 | C3, C4, C5, C6 | 4 311-1088-1-ND

2.2nF | CAP CER 2.2nF 50V X7R 0603 | C7 | 1 311-1081-1-ND

685119248123 | Micro HDMI Type D Receptacle WR-COM, Horizontal, SMT | J1 | 1 732-5254-1-ND

22R | Resistor 0603 22Ohm | R1 | 1 CR0603-JW- | 220ELFCT-ND

4.7k | Resistor 0603 4.7k Ohm | R2, R3, R4, R5 | 4 CR0603-JW- | 472ELFCT-ND

MIC5504-3.3YM5-TR | Single LDO, 2.5 to 5.5 V, Fixed Out 3.3 V, 0.3 A, -40 to 125 degC, 5-Pin SOT-23 (M5), RoHS, Tape and Reel | U1 | 1 576-4764-1-ND

SN65LVDT14PW | SPI<>LVDS Transceiver, 1 Tx and 4 Rx, -55 to +125 degC, 20-pin TSSOP (PW), Green (RoHS & no Sb/Br) | U2 | 1 296-12736-5-ND

TPD4E02B04DQAR | 4 Channel TVS Avalanch diode for USB3/HDMI2.0 protection | U3, U4, U5 | 3 296-43875-1-ND

MPU-6000 | 3-Axis Gyroscope 3-Axis Accelerometer Motion Processing Unit with I2C and SPI, 2.5, 3 or 3.3 V, -40 to 85 degC, 24-Pin QFN, RoHS, Tape and Reel | U6 | 1 1428-1005-1-ND






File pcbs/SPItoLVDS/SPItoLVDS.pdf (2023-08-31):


SRN 4 0 1 8 -4 R7 M | V IN E N G N D | 2

D 2 _P | | 8 | TPD 4 E 0 2B0 4 D QAR U 5

9 | 1 3 REFCL K_P 1 4 1 5

SPI _ IN T | 1 6 1 7

T IT L E PMOD S P I <> LVDS

PRO J Saw yer | CL IE N T Faceb o o k






Comment | Description | Designator | Quantity | Manufacturer | Supplier Part Number 1 | Supplier 1

10uF | CAP CER 10UF 0603 | C1, C2 | 2 | | 490-12736-1-ND | Digi-Key
0.1uF | CAP CER 0.1UF 16V X7R 0603 | C3, C4 | 2 YAGEO | | 311-1088-1-ND | Digi-Key

PMOD | PMOD Connector, Through Hole, Standard pinout | J1 | 1 | | 732-5354-ND | Digi-Key

685119134923 | HDMI Type A Receptacle WR-HDMI, Horizontal, SMT | J2 | 1 Wurth Elektronik | | 732-2737-1-ND | Digi-Key

SRN4018-4R7M | FIXED IND 4.7UH 1.9A 84 MOHM SMD | L1 | 1 Bourns | | SRN4018-4R7MCT-ND | Digi-Key

22R | Resistor 0603 22Ohm | R1 | 1 | | CR0603-JW-220ELFCT-ND | Digi-Key

TPS61222DCKR | Boost Voltage Converter with 0.7 to 5.5 V Input and 5 V Output, -40 to 85 degC, 6-Pin SC70 (DCK), Green (RoHS & no Sb/Br) | U1 | 1 Texas | Instruments | 296-39435-1-ND | Digi-Key

TPD4E02B04DQAR | 4 Channel TVS Avalanch diode for USB3/HDMI2.0 protection | U2, U3, U5 | 3 Texas | Instruments | 296-43875-1-ND | Digi-Key

SN65LVDT41PW | SPI<>LVDS Transceiver Interconnect Extender Chipset, -40 to +125 degC, 20-Pin TSSOP (PW), Green (RoHS & no Sb/Br) | U4 | 1 Texas | Instruments | 296-12738-5-ND | Digi-Key



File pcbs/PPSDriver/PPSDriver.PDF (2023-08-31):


TITL E PPS Dri ver Board

PRO J Saw yer | CL IE N T Faceb o o k







Comment | Designator | LibRef | Quantity | Supplier Part Number 1
0.1uF | C1, C2 | CAP-0603-0.1uF | 2 311-1088-1-ND
SMA Edge | J1, J3 | SMA_EDGE | 2 CON-SMA-EDGE-S- | ND
PMOD | J2 | PMOD-TH | 1 732-5354-ND
220R | R1, R2, R3, R5, R6, R7, R8, R9, R11, R12 | RES-0603-220R | 10 311-220GRCT-ND
100k | R4, R10 | RES-0603-100k | 2 YAG2294CT-ND
74LVT14D | U1, U2 | 74LVT14D | 2 1727-6371-1-ND

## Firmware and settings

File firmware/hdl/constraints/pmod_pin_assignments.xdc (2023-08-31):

# JX1 JA PMOD  (Digital Inputs)
set_property PACKAGE_PIN AB8  [get_ports {digital_input_0}];  # JX1_HP_DP_00_P
set_property PACKAGE_PIN AB7  [get_ports {digital_input_1}];  # JX1_HP_DP_00_N
set_property PACKAGE_PIN Y7   [get_ports {digital_input_2}];  # JX1_HP_DP_01_P
set_property PACKAGE_PIN AA7  [get_ports {digital_input_3}];  # JX1_HP_DP_01_N
set_property PACKAGE_PIN AA9  [get_ports {digital_input_4}];  # JX1_HP_DP_02_P
set_property PACKAGE_PIN AA8  [get_ports {digital_input_5}];  # JX1_HP_DP_02_N
set_property PACKAGE_PIN AC9  [get_ports {digital_input_6}];  # JX1_HP_DP_03_P
set_property PACKAGE_PIN AC8  [get_ports {digital_input_7}];  # JX1_HP_DP_03_N

set_property IOSTANDARD LVCMOS18 [get_ports {digital_input_0}]
set_property IOSTANDARD LVCMOS18 [get_ports {digital_input_1}]
set_property IOSTANDARD LVCMOS18 [get_ports {digital_input_2}]
set_property IOSTANDARD LVCMOS18 [get_ports {digital_input_3}]
set_property IOSTANDARD LVCMOS18 [get_ports {digital_input_4}]
set_property IOSTANDARD LVCMOS18 [get_ports {digital_input_5}]
set_property IOSTANDARD LVCMOS18 [get_ports {digital_input_6}]
set_property IOSTANDARD LVCMOS18 [get_ports {digital_input_7}]

# JX1 JB PMOD (Dual PPS)
set_property PACKAGE_PIN AD6  [get_ports {PPS_0}];  # JX1_HP_DP_04_P
set_property PACKAGE_PIN AD5  [get_ports {PPS_1}];  # JX1_HP_DP_04_N
set_property PACKAGE_PIN AD9  [get_ports {clk_10M}];  # JX1_HP_DP_05_P
# set_property PACKAGE_PIN AE9  [get_ports {PLPMOD2_D3}];  # JX1_HP_DP_05_N
# set_property PACKAGE_PIN AE7  [get_ports {PLPMOD2_D4}];  # JX1_HP_DP_06_P
# set_property PACKAGE_PIN AE6  [get_ports {PLPMOD2_D5}];  # JX1_HP_DP_06_N
# set_property PACKAGE_PIN AD8  [get_ports {PLPMOD2_D6}];  # JX1_HP_DP_07_P
# set_property PACKAGE_PIN AD7  [get_ports {PLPMOD2_D7}];  # JX1_HP_DP_07_N

set_property IOSTANDARD LVCMOS18 [get_ports {PPS_0}]
set_property IOSTANDARD LVCMOS18 [get_ports {PPS_1}]
set_property IOSTANDARD LVCMOS18 [get_ports {clk_10M}]
# set_property IOSTANDARD LVCMOS18 [get_ports {PLPMOD2_D3}]
# set_property IOSTANDARD LVCMOS18 [get_ports {PLPMOD2_D4}]
# set_property IOSTANDARD LVCMOS18 [get_ports {PLPMOD2_D5}]
# set_property IOSTANDARD LVCMOS18 [get_ports {PLPMOD2_D6}]
# set_property IOSTANDARD LVCMOS18 [get_ports {PLPMOD2_D7}]

# JX1 JC PMOD (ADC 0)
set_property PACKAGE_PIN AA4  [get_ports {adc_0_spi_cs}];  # JX1_HP_DP_08_P
# set_property PACKAGE_PIN AA3  [get_ports {PLPMOD3_D1}];  # JX1_HP_DP_08_N
set_property PACKAGE_PIN W1   [get_ports {adc_0_spi_miso}];  # JX1_HP_DP_09_P
set_property PACKAGE_PIN Y1   [get_ports {adc_0_spi_clk}];  # JX1_HP_DP_09_N
# set_property PACKAGE_PIN W4   [get_ports {PLPMOD3_D4}];  # JX1_HP_DP_10_P
# set_property PACKAGE_PIN Y4   [get_ports {PLPMOD3_D5}];  # JX1_HP_DP_10_N
# set_property PACKAGE_PIN AB2  [get_ports {PLPMOD3_D6}];  # JX1_HP_DP_11_P
# set_property PACKAGE_PIN AB1  [get_ports {PLPMOD3_D7}];  # JX1_HP_DP_11_N

set_property IOSTANDARD LVCMOS18 [get_ports {adc_0_spi_cs}]
# set_property IOSTANDARD LVCMOS18 [get_ports {PLPMOD3_D1}]
set_property IOSTANDARD LVCMOS18 [get_ports {adc_0_spi_miso}]
set_property IOSTANDARD LVCMOS18 [get_ports {adc_0_spi_clk}]
# set_property IOSTANDARD LVCMOS18 [get_ports {PLPMOD3_D4}]
# set_property IOSTANDARD LVCMOS18 [get_ports {PLPMOD3_D5}]
# set_property IOSTANDARD LVCMOS18 [get_ports {PLPMOD3_D6}]
# set_property IOSTANDARD LVCMOS18 [get_ports {PLPMOD3_D7}]

# JX1 JD PMOD (ADC 1)
set_property PACKAGE_PIN W3   [get_ports {adc_1_spi_cs}];  # JX1_HP_DP_12_P
# set_property PACKAGE_PIN W2   [get_ports {PLPMOD4_D1}];  # JX1_HP_DP_12_N
set_property PACKAGE_PIN AB6  [get_ports {adc_1_spi_miso}];  # JX1_HP_DP_13_P
set_property PACKAGE_PIN AC6  [get_ports {adc_1_spi_clk}];  # JX1_HP_DP_13_N
# set_property PACKAGE_PIN Y2   [get_ports {PLPMOD4_D4}];  # JX1_HP_DP_14_P
# set_property PACKAGE_PIN AA2  [get_ports {PLPMOD4_D5}];  # JX1_HP_DP_14_N
# set_property PACKAGE_PIN AE4  [get_ports {PLPMOD4_D6}];  # JX1_HP_DP_15_P
# set_property PACKAGE_PIN AE3  [get_ports {PLPMOD4_D7}];  # JX1_HP_DP_15_N

set_property IOSTANDARD LVCMOS18 [get_ports {adc_1_spi_cs}]
# set_property IOSTANDARD LVCMOS18 [get_ports {PLPMOD4_D1}]
set_property IOSTANDARD LVCMOS18 [get_ports {adc_1_spi_miso}]
set_property IOSTANDARD LVCMOS18 [get_ports {adc_1_spi_clk}]
# set_property IOSTANDARD LVCMOS18 [get_ports {PLPMOD4_D4}]
# set_property IOSTANDARD LVCMOS18 [get_ports {PLPMOD4_D5}]
# set_property IOSTANDARD LVCMOS18 [get_ports {PLPMOD4_D6}]
# set_property IOSTANDARD LVCMOS18 [get_ports {PLPMOD4_D7}]
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

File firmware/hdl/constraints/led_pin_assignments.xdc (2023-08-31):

# User LEDs
set_property PACKAGE_PIN R7  [get_ports {digital_inputs_0_fault}];  # JX1_HP_DP_25_P
set_property PACKAGE_PIN T5  [get_ports {imu_0_fault}];  # JX1_HP_DP_24_P
set_property PACKAGE_PIN T7  [get_ports {adc_0_fault}];  # JX1_HP_DP_25_N
set_property PACKAGE_PIN T4  [get_ports {adc_1_fault}];  # JX1_HP_DP_24_N
set_property PACKAGE_PIN T3  [get_ports {adc_2_fault}];  # JX1_HP_DP_27_P
set_property PACKAGE_PIN U2  [get_ports {adc_3_fault}];  # JX1_HP_DP_27_N
set_property PACKAGE_PIN U6  [get_ports {traffic_generator_0_fault}];  # JX1_HP_DP_26_P
# set_property PACKAGE_PIN W7   [get_ports {PLPMOD6_D7}];  # JX1_HP_DP_23_N

set_property IOSTANDARD LVCMOS18 [get_ports {digital_inputs_0_fault}]
set_property IOSTANDARD LVCMOS18 [get_ports {imu_0_fault}]
set_property IOSTANDARD LVCMOS18 [get_ports {adc_0_fault}]
set_property IOSTANDARD LVCMOS18 [get_ports {adc_1_fault}]
set_property IOSTANDARD LVCMOS18 [get_ports {adc_2_fault}]
set_property IOSTANDARD LVCMOS18 [get_ports {adc_3_fault}]
set_property IOSTANDARD LVCMOS18 [get_ports {traffic_generator_0_fault}]
# set_property IOSTANDARD LVCMOS18 [get_ports {PLPMOD6_D7}]
